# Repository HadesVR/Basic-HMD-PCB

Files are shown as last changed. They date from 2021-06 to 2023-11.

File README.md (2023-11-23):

# HadesVR Basic HMD 

The HadesVR Basic HMD is a PCB that helps you convert any "Phone VR" headset into a PC VR headset. It's intended to be used with the [Wand controller pcbs](https://github.com/HadesVR/Wand-Controller) as a kit to get you started, however it can be used standalone or with other DIY controllers.

The PCB addds support for all the electronics required to connect to a PC, get rotation data from the headset and get controller and tracker data wirelessly in a 100x35mm board with no SMD components.

Revision 2 of the board comes with a few improvements, namely more filtering for the 3,3v rail, support for 3.3v only IMU's, optional dual RF modules for better RF performance and better mounting holes. All while keeping the board simple and easy to build by a beginner.

The new Revision 2 firmware also adds support for easy Serial calibration, just plug in your board, open the serial monitor and follow the steps on the screen to calibrate. This new firmware can detect if the board is a Rev 1 board or if it's a Rev 2 board and configure itself accordingly, meaning it's fully backwards compatible with Rev 1 boards.

The Basic HMD PCB uses an Arduino Pro Micro as it's core, an MPU9250 as IMU (though it can be replaced by something like a BNO085 for better results if you're feeling like modifying the code a little), and an NRF24L01 to receive data from controllers and trackers. It also has hardware support for an RGB LED to use with a ping pong ball for 6dof tracking using PSMoveService.

Do note that any IMU supported by the [FastIMU](https://github.com/LiquidCGS/FastIMU) library is supported, however it is strongly recommended that an IMU with a built in magnetometer is used for the best experience. 

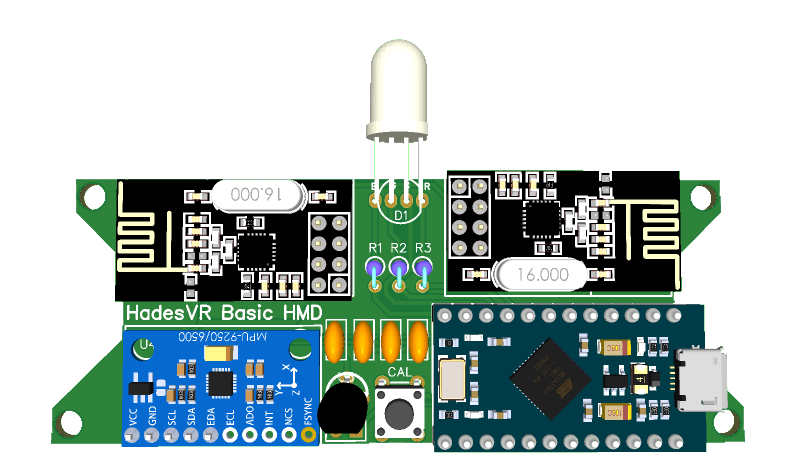
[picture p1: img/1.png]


## Hardware Needed

| Component | Purpose | Notes | Amount |
| --- | --- | ----- | --- |
| Arduino Pro Micro* | Used to interface with PC through HID | **Not** an Arduino nano or a pro mini, those can't do USB HID. | 1 |
| IMU** | Used to gather rotation data from the headset | The IMU should sit flat against the pcb, this means you'll need to remove the black spacers on the pin headers after soldering them to the IMU. | 1 | 
| NRF24L01***  | Used to receive wireless data from controllers / trackers | - | 1/2 | 
| HT7533 voltage regulator | Used to regulate voltage for the IMU and RF receiver | HT7333 or MCP1700-3302E are also compatible. The board is designed for the TO-92 package of both of them. | 1 |
| 470nF capacitor | Used to smooth out the input and output regulator voltage. | - | 4 | 
| 5mm RGB LED | Used for 6dof tracking | Common anode or common cathode are both supported. | 1 |
| 6x6 tact switch| Used to enter magnetic calibration mode | - | 1 |
| 120Ω Resistor | Used to limit the current for the green and blue colors of the LED | 1/4w | 2 |
| 180Ω Resistor | Used to limit the current for the Red color of the LED | 1/4w | 1 |
| White ping pong ball | Used to difuse the LED's light for 6dof tracking | Any will do as long as it's white and 40mm in diameter | 1 |
| 3D printable cup | Holds the tracking ball against the LED and makes it so the light is diffused evenly. | ~~3D printable file not yet ready, sorry!~~ | 1 | 

*⚠️ Not an Arduino Micro either, not only will it not fit, it has a completly different pinout!!!! you need an **Arduino Pro Micro** for this build.

**Any 3.3v IMU with that same pinout will work as long as it's supported by the [FastIMU](https://github.com/LiquidCGS/FastIMU) library, which was made mainly for HadesVR.

***Dual NRF24L01's are recommended, each one in charge of receiving the data for one controller, that way latency is kept to a minimum, however the board *can with a single one* if the secondary NRF24L01 is not found on startup.

## Building the board

### ⚠️If you've got a Rev 2.1 board, you need to solder the voltage regulator in the *opposite direction* to what is on the silkscreen, this is due to an error with the footprint in that specific hardware version. Rev 2.2 boards fix this mistake.

The board only has a few components, they all go on the top layer and can be soldered in any order though you might find it easier to leave the calibration tact switch for last.

The IMU should be mounted as flat against the board as possible to minimize an offset angle, to do this you will have to remove the black plastic separator from the pin headers:

* Put your IMU and it's pin headers on a breadboard and make sure it's straight
* Solder the pin headers to the IMU
* **Carefully** remove the black plastic bit on the pins under the IMU with a box cutter or an exacto knife
* Solder it to the HMD PCB.

The end result should look something like this:

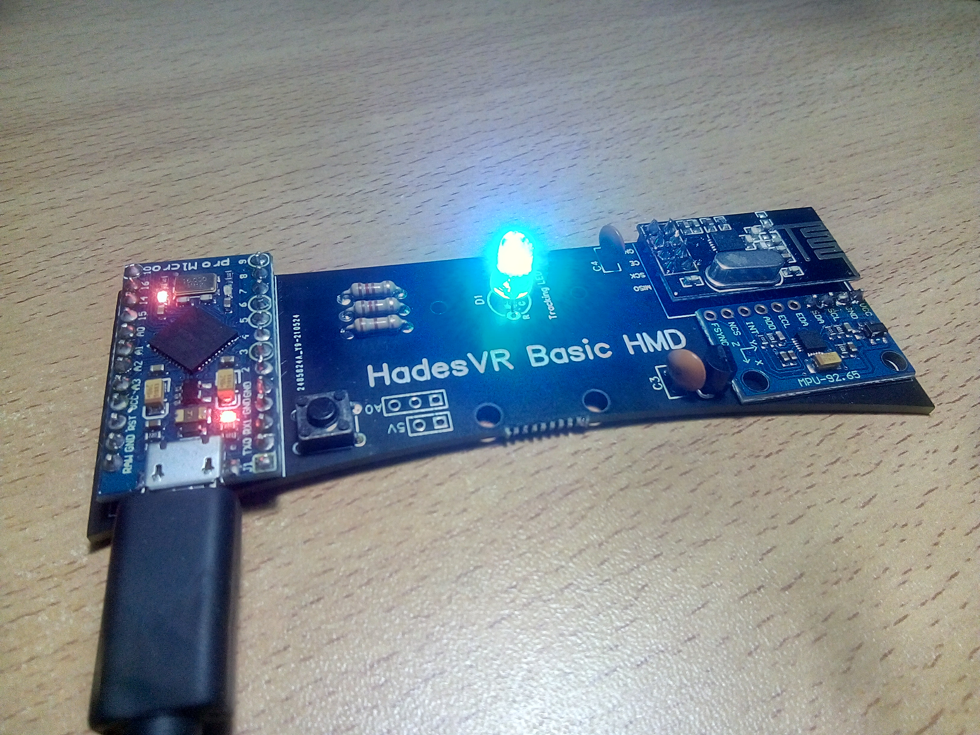
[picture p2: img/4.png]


## Uploading the firmware and calibrating the sensors

To upload the firmware you will need to have the [RF24 Arduino Library](https://github.com/nRF24/RF24) installed in your [Arduino IDE](https://www.arduino.cc/en/software).
You will also need the [FastIMU](https://github.com/LiquidCGS/FastIMU) library installed.

You can download both required libraries using the Library manager from within the Arduino IDE. 

* Open "Firmware.ino" which is situated inside the Calibration folder inside the firmware folder with the arduino IDE.
* Set up your IMU address and IMU type. if you're unsure of the address or type you can use the IMUIdentifier example sketch provided with the FastIMU library.
* if your LED is Common cathode you'll need to uncomment `#define COMMON_CATHODE` for it to work, if it's Common anode you won't need to change anything.
* Set up your IMU geometry if it's different than the default 
* If you're gonna calibrate the board for the first time I recommend calibrating it "flat", so leave `#define CALIBRATE_FLAT` uncommented. This means the bottom of the board must be flat and paralell against the ground when calibrating. if your board is mounted vertically to a headset you should comment this line.
* Select "Arduino Leonardo" in the boards menu.
* Plug in your HMD board and select the COM port your Arduino Pro Micro is in (might come up as Arduino Leonardo).
* Click upload and wait for the upload to be done.
* LED should light up White and stay blinking. This means there is no calibration data stored on the EEPROM.
* Open the serial monitor and follow the steps to calibrate the accelerometer/gyro and magnetometer if you have one.
* Once done, the LED will turn blue, this is your prompt to close the serial monitor as the IMU calibration has finished, the values will be saved to EEPROM.  If you need to recalibrate the board, simply restart the board and open the serial monitor again.

If your view is crooked or too drifty you might need to calibrate your magnetometer, accelerometer and gyroscope again, to do that simply open the Serial monitor and follow the instructions!

Once you have the firmware.ino sketch uploaded to the board and you've done all calibration procedures you can press the button to change the tracking color of the ball. I recomended you either use green blue or red.

## Getting HID values

To configure the driver you will need the VID and PID values from the board you're using. The easiest way of getting them is going to the Arduino IDE, clicking on tools and clicking on get board info with the HMD plugged in:

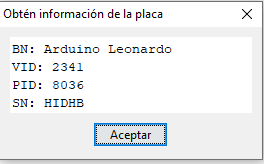
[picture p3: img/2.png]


Do note these values are in HEX so to use them in the driver config file you'll need to convert them to decimal numbers.
to do that you can use websites like [Rapidtables](https://www.rapidtables.com/convert/number/hex-to-decimal.html), just input your VID and PID values one at a time and convert them to decimal numbers.

#### IMPORTANT NOTE: If you're using arduino IDE 2.0.x, there's a bug that makes it so that some arduino boards display the wrong PID value, try the default one set with the driver first and if that doesn't work you'll have to check them from device manager.

Once done, you'll get values like these and then all you have to do is load them up in your driver config file. For more details on driver configuration, check out the driver configuration docs over at the main repo.



## Color codes
If something's wrong with your board the tracking LED will turn a few different colors. You can uncomment `#define SERIAL_DEBUG` to see the startup process in more detail:

| LED pulses | Description |
| --- | --- |
| Blinking YELLOW | Error connecting to the Main NRF module. |
| Blinking RED | Error initializing IMU |
| Blinking WHITE | Calibration data is invalid, must redo calibration |

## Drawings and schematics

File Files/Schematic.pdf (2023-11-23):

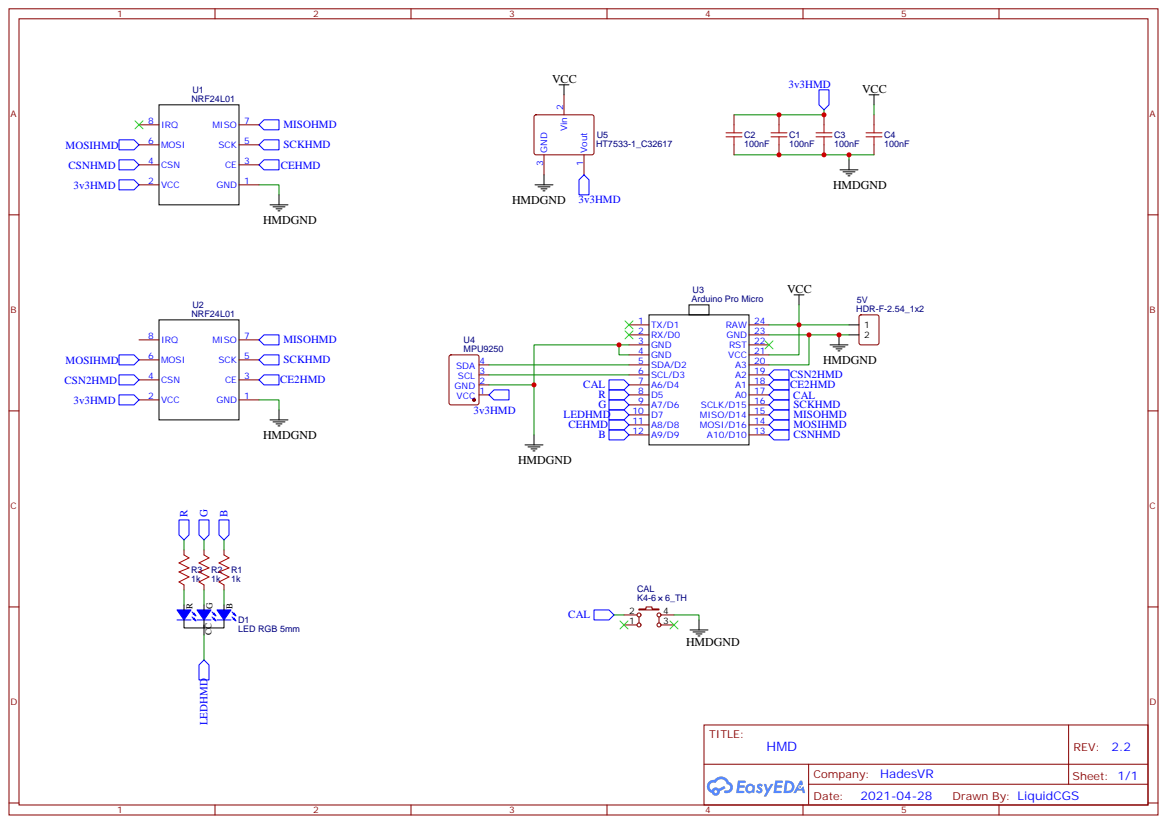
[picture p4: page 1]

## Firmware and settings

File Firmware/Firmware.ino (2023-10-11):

/*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
  The above copyright notice and this permission notice shall be included in all copies or substantial portions of the Software.

  THE SOFTWARE IS PROVIDED "AS IS", WITHOUT WARRANTY OF ANY KIND, EXPRESS OR IMPLIED,INCLUDING BUT NOT LIMITED TO
  THE WARRANTIES OF MERCHANTABILITY, FITNESS FOR A PARTICULAR PURPOSE AND NONINFRINGEMENT. IN NO EVENT SHALL THE
  AUTHORS OR COPYRIGHT HOLDERS BE LIABLE FOR ANY CLAIM, DAMAGES OR OTHER LIABILITY, WHETHER IN AN ACTION OF CONTRACT,
  TORT OR OTHERWISE, ARISING FROM, OUT OF OR IN CONNECTION WITH THE SOFTWARE OR THE USE OR OTHER DEALINGS IN THE SOFTWARE.
*/

#include <Wire.h>
#include <EEPROM.h>
#include <SPI.h>
#include "RF24.h"
#include "HID.h"
#include "FastIMU.h"

//==========================================================================================================
//************************************ USER CONFIGURABLE STUFF HERE ****************************************
//==========================================================================================================

#define IMU_ADDRESS     0x68                // You can find it out by using the IMUIdentifier example
MPU9250 IMU;                                // IMU type
#define COMMON_CATHODE                      // Uncomment this if your LED is common cathode
#define USE_RF                              // Comment this to disable RF functionality.
#define IMU_GEOMTERY 6                      // Change to your current IMU geomtery (check FastIMU docs for a reference pic).
#define CALIBRATE_FLAT                      // If left uncommented accelerometer/gyro calibration must be done with the flat side of the board pointing down.
//#define SERIAL_DEBUG                        // Uncomment this to make the serial port spicy.

//==========================================================================================================
//************************************ DATA TRANSPORT LAYER ************************************************
//==========================================================================================================

static const uint8_t USB_HID_Descriptor[] PROGMEM = {

  0x06, 0x03, 0x00,   // USAGE_PAGE (vendor defined)
  0x09, 0x00,         // USAGE (Undefined)
  0xa1, 0x01,         // COLLECTION (Application)
  0x15, 0x00,         //   LOGICAL_MINIMUM (0)
  0x26, 0xff, 0x00,   //   LOGICAL_MAXIMUM (255)
  0x85, 0x01,         //   REPORT_ID (1)
  0x75, 0x08,         //   REPORT_SIZE (16)
  0x95, 0x3f,         //   REPORT_COUNT (1)
  0x09, 0x00,         //   USAGE (Undefined)
  0x81, 0x02,         //   INPUT (Data,Var,Abs) - to the host
  0xc0
};

//==========================================================================================================
//************************************* Data packet stuff *************************************************
//==========================================================================================================
struct HMDRAWPacket
{
  uint8_t  PacketID;

  int16_t AccX;
  int16_t AccY;
  int16_t AccZ;

  int16_t GyroX;
  int16_t GyroY;
  int16_t GyroZ;

  int16_t MagX;
  int16_t MagY;
  int16_t MagZ;

  uint16_t HMDData;

  int16_t tracker1_QuatW;
  int16_t tracker1_QuatX;
  int16_t tracker1_QuatY;
  int16_t tracker1_QuatZ;
  uint8_t tracker1_vBat;
  uint8_t tracker1_data;

  int16_t tracker2_QuatW;
  int16_t tracker2_QuatX;
  int16_t tracker2_QuatY;
  int16_t tracker2_QuatZ;
  uint8_t tracker2_vBat;
  uint8_t tracker2_data;

  int16_t tracker3_QuatW;
  int16_t tracker3_QuatX;
  int16_t tracker3_QuatY;
  int16_t tracker3_QuatZ;
  uint8_t tracker3_vBat;
  uint8_t tracker3_data;

};
struct ControllerPacket
{
  uint8_t PacketID;
  int16_t Ctrl1_QuatW;
  int16_t Ctrl1_QuatX;
  int16_t Ctrl1_QuatY;
  int16_t Ctrl1_QuatZ;
  int16_t Ctrl1_AccelX;
  int16_t Ctrl1_AccelY;
  int16_t Ctrl1_AccelZ;
  uint16_t Ctrl1_Buttons;
  uint8_t Ctrl1_Trigger;
  int8_t Ctrl1_axisX;
  int8_t Ctrl1_axisY;
  int8_t Ctrl1_trackY;
  uint8_t Ctrl1_vBat;
  uint8_t Ctrl1_THUMB;
  uint8_t Ctrl1_INDEX;
  uint8_t Ctrl1_MIDDLE;
  uint8_t Ctrl1_RING;
  uint8_t Ctrl1_PINKY;
  uint8_t Ctrl1_AnalogGrip;
  uint16_t Ctrl1_Data;

  int16_t Ctrl2_QuatW;
  int16_t Ctrl2_QuatX;
  int16_t Ctrl2_QuatY;
  int16_t Ctrl2_QuatZ;
  int16_t Ctrl2_AccelX;
  int16_t Ctrl2_AccelY;
  int16_t Ctrl2_AccelZ;
  uint16_t Ctrl2_Buttons;
  uint8_t Ctrl2_Trigger;
  int8_t Ctrl2_axisX;
  int8_t Ctrl2_axisY;
  int8_t Ctrl2_trackY;
  uint8_t Ctrl2_vBat;
  uint8_t Ctrl2_THUMB;
  uint8_t Ctrl2_INDEX;
  uint8_t Ctrl2_MIDDLE;
  uint8_t Ctrl2_RING;
  uint8_t Ctrl2_PINKY;
  uint8_t Ctrl2_AnalogGrip;
  uint16_t Ctrl2_Data;
};

static HMDRAWPacket HMDRawData;
static ControllerPacket ContData;
//==========================================================================================================
//**************************************** RF Data stuff ***************************************************
//==========================================================================================================
const uint64_t rightCtrlPipe = 0xF0F0F0F0E1LL;
const uint64_t leftCtrlPipe = 0xF0F0F0F0D2LL;

RF24 radio1(8, 10); // CE, CSN on radio 1
RF24 radio2(A1, A2); // CE, CSN on radio 2

bool newCtrlData = false;
//==========================================================================================================
//**************************************** IMU variables ***************************************************
//==========================================================================================================
AccelData IMUAccel;
GyroData IMUGyro;
MagData IMUMag;
calData calib = {0};
//==========================================================================================================

#define CALPIN  4
#define CE2     A1
#define CSN2    A2
#define CE1     8
#define CSN1    10

int ledColor = 0;
bool calPressed = false;
bool revTwoBoard = false;
bool serialOpened = false;
bool calNotDone = false;

void setup() {
  //Setup Serial
  Serial.begin(115200);

  //Setup HID SubDescriptor
  static HIDSubDescriptor node(USB_HID_Descriptor, sizeof(USB_HID_Descriptor));
  HID().AppendDescriptor(&node);

  //Setup IO
  pinMode(7, OUTPUT);
  pinMode(5, OUTPUT);
  pinMode(6, OUTPUT);
  pinMode(9, OUTPUT);
  pinMode(A0, INPUT);
  pinMode(CALPIN, INPUT_PULLUP);

  //turn on LED
  setColor(7);

#ifdef SERIAL_DEBUG
  while (!Serial) ;
  debugPrintln("[INFO]\tSerial debug active");
#endif

  //Check board revision
  pinMode(A3, INPUT_PULLUP);
  if (digitalRead(A3)) {
    debugPrintln("[INFO]\tBoard revision: 1.X");
    revTwoBoard = false;
  }
  else {
    debugPrintln("[INFO]\tBoard revision: 2.X");
    revTwoBoard = true;
  }

  //Set up RF radios
#ifdef USE_RF
  //start up radio 1
  radio1.begin();
  radio1.setPayloadSize(32);
  radio1.setAutoAck(false);
  radio1.setDataRate(RF24_2MBPS);
  radio1.setPALevel(RF24_PA_LOW);
  radio1.startListening();
  //start up radio 2
  if (revTwoBoard) {
    radio2.begin();
    radio2.setPayloadSize(32);
    radio2.setAutoAck(false);
    radio2.setDataRate(RF24_2MBPS);
    radio2.setPALevel(RF24_PA_LOW);
    radio2.startListening();
  }
  if (!radio1.isChipConnected())
  {
    debugPrintln("[ERROR]\tRadio 1 Not Found!");
    errorBlink(1);    //Radio 1 is the main radio, shouldn't run without it.
  }
  else {
    debugPrintln("[INFO]\tRadio 1 Initialized");
    radio1.openReadingPipe(1, rightCtrlPipe);
    if (!revTwoBoard) {
      radio1.openReadingPipe(2, leftCtrlPipe);
    }
  }
  if (revTwoBoard) {
    if (!radio2.isChipConnected())
    {
      debugPrintln("[ERROR]\tRadio 2 Not Found!");
      debugPrintln("[INFO]\tFalling back to single radio mode");
      radio1.openReadingPipe(2, leftCtrlPipe);
    }
    else
    {
      debugPrintln("[INFO]\tRadio 2 Initialized");
      radio2.openReadingPipe(1, leftCtrlPipe);
    }
  }
#endif

  //Start up I2C
  Wire.begin();
  Wire.setClock(400000); //400khz clock

  //Initialize IMU
  IMU.setIMUGeometry(IMU_GEOMTERY);
  int err = IMU.init(calib, IMU_ADDRESS);
  if (err != 0)
  {
    debugPrint("[ERROR]\tIMU ERROR: ");
    debugPrintln(err);
    errorBlink(0);
  }
  debugPrintln("[INFO]\tIMU Initialized.");

  EEPROM.get(100, ledColor);
  if (ledColor > 6) {
    ledColor = 0;
  }
  setColor(ledColor);

  HMDRawData.PacketID = 3;
  ContData.PacketID = 2;

  int t;
  EEPROM.get(125, t);
  if (!(t == 99)) {
    debugPrintln("[INFO]\tCalibration not valid!");
    calNotDone = true;
    while (!Serial) {
      setColor(6);
      delay(500);
      setColor(7);
      delay(500);
    }
  }
  else {
    //calibration is valid
    EEPROM.get(200, calib);
    IMU.init(calib, IMU_ADDRESS);     //Reinitialize with correct calibration values
    debugPrintln("[INFO]\tLoaded Calibration from EEPROM!");
#ifdef SERIAL_DEBUG
    printCalibration();
#endif
  }
}

void loop()
{
  //run Serial
  if (Serial) {
    if (!serialOpened) {
      if (calNotDone) {
        Serial.println("[INFO]\tNo calibration data detected, do you want to enter calibration mode? (y/n)");
      } else {
        Serial.println("[INFO]\tSerial monitor open, do you want to enter calibration mode? (y/n)");
      }
    }
    serialOpened = true;
    if (Serial.read() == 'y') {
      setColor(7);
      calib = { 0 };                    //this looks important
#ifdef CALIBRATE_FLAT
      IMU.setIMUGeometry(0);
#endif
      IMU.init(calib, IMU_ADDRESS);
      Serial.println("[INFO]\tCalibrating IMU... Keep headset still on a flat and level surface...");
      delay(10000);
      IMU.calibrateAccelGyro(&calib);
      IMU.init(calib, IMU_ADDRESS);
      Serial.println("[INFO]\tAccelerometer and Gyroscope calibrated!");
      if (IMU.hasMagnetometer()) {
        delay(1000);
        Serial.println("[INFO]\tMagnetometer calibration: move IMU in figure 8 pattern until done.");
        delay(5000);
        IMU.calibrateMag(&calib);
        Serial.println("[INFO]\tMagnetic calibration done!");
      }
      Serial.println("[INFO]\tIMU Calibration complete!");
      Serial.println("[INFO]\tAccel biases X/Y/Z: ");
      Serial.print("[INFO]\t");
      Serial.print(calib.accelBias[0]);
      Serial.print(", ");
      Serial.print(calib.accelBias[1]);
      Serial.print(", ");
      Serial.println(calib.accelBias[2]);
      Serial.println("[INFO]\tGyro biases X/Y/Z: ");
      Serial.print("[INFO]\t");
      Serial.print(calib.gyroBias[0]);
      Serial.print(", ");
      Serial.print(calib.gyroBias[1]);
      Serial.print(", ");
      Serial.println(calib.gyroBias[2]);
      if (IMU.hasMagnetometer()) {
        Serial.println("[INFO]\tMag biases X/Y/Z: ");
        Serial.print("[INFO]\t");
        Serial.print(calib.magBias[0]);
        Serial.print(", ");
        Serial.print(calib.magBias[1]);
        Serial.print(", ");
        Serial.println(calib.magBias[2]);
        Serial.println("[INFO]\tMag Scale X/Y/Z: ");
        Serial.print("[INFO]\t");
        Serial.print(calib.magScale[0]);
        Serial.print(", ");
        Serial.print(calib.magScale[1]);
        Serial.print(", ");
        Serial.println(calib.magScale[2]);
      }
      setColor(4);
      Serial.println("[INFO]\tSaving Calibration values to EEPROM!");
      EEPROM.put(200, calib);
      EEPROM.put(125, 99);
      delay(1000);
      Serial.println("[INFO]\tYou can now close the Serial monitor.");
      delay(5000);
      IMU.setIMUGeometry(IMU_GEOMTERY);
      IMU.init(calib, IMU_ADDRESS);
      setColor(ledColor);
    }
  }

  //run IMU
  IMU.update();
  IMU.getAccel(&IMUAccel);
  IMU.getGyro(&IMUGyro);

  if (IMU.hasMagnetometer()) {
    IMU.getMag(&IMUMag);
    HMDRawData.MagX = (short)(IMUMag.magX * 5);
    HMDRawData.MagY = (short)(IMUMag.magY * 5);
    HMDRawData.MagZ = (short)(IMUMag.magZ * 5);
  }
  else {
    HMDRawData.MagX = (short)(0);
    HMDRawData.MagY = (short)(0);
    HMDRawData.MagZ = (short)(0);
  }

  HMDRawData.AccX = (short)(IMUAccel.accelX * 2048);
  HMDRawData.AccY = (short)(IMUAccel.accelY * 2048);
  HMDRawData.AccZ = (short)(IMUAccel.accelZ * 2048);

  HMDRawData.GyroX = (short)(IMUGyro.gyroX * 16);
  HMDRawData.GyroY = (short)(IMUGyro.gyroY * 16);
  HMDRawData.GyroZ = (short)(IMUGyro.gyroZ * 16);

  //run RF
  uint8_t pipenum;
  if (radio1.available(&pipenum)) {                  //thanks SimLeek for this idea!
    if (pipenum == 1) {
      radio1.read(&ContData.Ctrl1_QuatW, 29);        //receive right controller data
      //debugPrintln("RX 1, Right Controller!");
      newCtrlData = true;
    }
    if (pipenum == 2) {
      radio1.read(&ContData.Ctrl2_QuatW, 29);        //receive left controller data
      //debugPrintln("RX 1, Left Controller!");
      newCtrlData = true;
    }
  }
  if (radio2.available(&pipenum) && revTwoBoard) {
    radio2.read(&ContData.Ctrl2_QuatW, 29);        //receive left controller data
    //debugPrintln("RX 2, Left controller!");
    newCtrlData = true;
  }
  if (newCtrlData) {
    HID().SendReport(1, &ContData, 63);
    newCtrlData = false;
  }

  //run LED
  if (!digitalRead(CALPIN)) {
    if (!calPressed) {
      calPressed = true;
      ledColor++;
      if (ledColor > 6) {
        ledColor = 0;
      }
      debugPrintln("[INFO]\tswitched LED color and saved new value");
      setColor(ledColor);
      EEPROM.put(100, ledColor);
      delay(40);
    }
  }
  else {
    calPressed = false;
  }
  HID().SendReport(1, &HMDRawData, 63);
}

void printCalibration()
{
  Serial.println("[INFO]\tAccel biases X/Y/Z: ");
  Serial.print("[INFO]\t");
  Serial.print(calib.accelBias[0]);
  Serial.print(", ");
  Serial.print(calib.accelBias[1]);
  Serial.print(", ");
  Serial.println(calib.accelBias[2]);
  Serial.println("[INFO]\tGyro biases X/Y/Z: ");
  Serial.print("[INFO]\t");
  Serial.print(calib.gyroBias[0]);
  Serial.print(", ");
  Serial.print(calib.gyroBias[1]);
  Serial.print(", ");
  Serial.println(calib.gyroBias[2]);
  if (IMU.hasMagnetometer()) {
    Serial.println("[INFO]\tMag biases X/Y/Z: ");
    Serial.print("[INFO]\t");
    Serial.print(calib.magBias[0]);
    Serial.print(", ");
    Serial.print(calib.magBias[1]);
    Serial.print(", ");
    Serial.println(calib.magBias[2]);
    Serial.println("[INFO]\tMag Scale X/Y/Z: ");
    Serial.print("[INFO]\t");
    Serial.print(calib.magScale[0]);
    Serial.print(", ");
    Serial.print(calib.magScale[1]);
    Serial.print(", ");
    Serial.println(calib.magScale[2]);
  }
}
void ledControl(int red, int green, int blue)
{
#ifdef COMMON_CATHODE
  digitalWrite(7, LOW);
  digitalWrite(5, red);
  digitalWrite(6, green);
  digitalWrite(9, blue);
#else
  digitalWrite(7, HIGH);
  digitalWrite(5, !red);
  digitalWrite(6, !green);
  digitalWrite(9, !blue);
#endif
}

void setColor(int index) {
  switch (index) {
    case 0:
      ledControl(1, 0, 0);    //red
      break;
    case 1:
      ledControl(1, 1, 0);    //yellow
      break;
    case 2:
      ledControl(0, 1, 0);    //green
      break;
    case 3:
      ledControl(0, 1, 1);    //cyan
      break;
    case 4:
      ledControl(0, 0, 1);    //blue
      break;
    case 5:
      ledControl(1, 0, 1);    //magenta
      break;
    case 6:
      ledControl(0, 0, 0);    //off
      break;
    case 7:
      ledControl(1, 1, 1);    //white
      break;
    default:
      ledControl(1, 0, 0);    //red again
      break;
  }
}

void debugPrint(String arg) {
#ifdef SERIAL_DEBUG
  Serial.print(arg);
#endif
}
void debugPrint(int arg) {
#ifdef SERIAL_DEBUG
  Serial.print(arg);
#endif
}
void debugPrintln(String arg) {
#ifdef SERIAL_DEBUG
  Serial.println(arg);
#endif
}
void debugPrintln(int arg) {
#ifdef SERIAL_DEBUG
  Serial.println(arg);
#endif
}

void errorBlink(int color)
{
  while (true)
  {
    setColor(color);
    delay(500);
    setColor(6);
    delay(500);
  }
}

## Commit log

2021-06-02 More error codes just in case
    [Firmware.ino]
2021-06-30 Dumb LED color switching stuff
2021-07-01 fix led stuff making things laggy
    [Firmware.ino]
2021-07-01 Led control stuff
2021-07-09 Arduino pro micro and arduino micro are different things.
2021-07-24 Larger regulator package for easier assembly
    [HMD.schdoc, PCB.pcbdoc]
2021-07-27 Added 3.3v reg package
2021-07-29 Larger LED package
    [PCB.pcbdoc]
2021-08-04 Firmware now works properly with driver version 1.23
2021-08-18 New raw sensor data packet code
2021-08-18 Updated the calibration guide for the new code
2021-08-20 Shrunk boards to fit in 100x100mm
2021-08-20 Update Gerber_PCB_HMD + CONTROLLERS.zip
2023-10-09 Rev 2 boards
    [HMD.schdoc, PCB.pcbdoc]
2023-10-11 Add calibrate flat, moved some stuff around.
2023-11-23 Fix dodgy footprint

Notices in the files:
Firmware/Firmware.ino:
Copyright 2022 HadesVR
